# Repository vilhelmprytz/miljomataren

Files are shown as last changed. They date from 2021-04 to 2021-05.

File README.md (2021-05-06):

# miljomataren



| Build | Type | Build Status |
| --- | --- | --- |
| Travis CI | Code Style |  |
| GitLab CI | [Container Registry](https://gitlab.com/vilhelm/miljomataren/container_registry) |  |

Diploma project "miljömätaren". Fullstack web application deployable using Docker.

## Introduction

This project aims to assemble a meter that sits in the air conditioning vents of a car’s instrument panel and shows real-time driving costs, fuel consumption, and carbon emissions using a display.

The project consists of three main components. The first component of this project is the physical gauge installed in the car’s instrument panel. The housing for the gauge is 3D-printed and designed using CAD software (Fusion 360). It contains an LCD connected to a microcontroller board called Arduino MKR GSM 1400. The Arduino board has cellular connectivity (GSM/2G), meaning it can fetch and send data to servers on the internet. To the Arduino, a GPS module with an associated antenna was attached. The Arduino was then able to locate the current position of the automobile and send it to a server using cellular connectivity. The display was used to show the real-time cost and carbon emissions of the current trip, as calculated by the server.

The second component of the project is the web application API (Application Programming Interface). The API was written in a programming language called Python together with a library called Flask. The API was configured to run on a server in the cloud. The Arduino microcontroller was configured to communicate with this API. The API was responsible for user authentication, receiving GPS positioning and calculating carbon emissions and real-time cost of current and past trips. The API uses [Google Sign-In](https://developers.google.com/identity/sign-in/web/sign-in) for authentication.

The third component of this project is the web application frontend. The frontend is a separate application, written separately from the API. The front end was coded to use the API to show statistics to the end-user on a web page. The frontend was coded in JavaScript using a framework called React.

## Structure

| Codebase | Description |
| :--- | :---: |
| [abernathy](abernathy) | Next.js frontend |
| [lowe](lowe) |  Flask backend |
| [delos](delos) | Arduino code |

## Equipment

- Arduino MKR GSM 1400
- LCD module compatible with Hitachi HD44780 driver. [Datasheet](https://www.electrokit.com/uploads/productfile/41014/JHD202C.pdf) for the one used in this project.
- GPS module such as [GPS breakout board FGPMMOPA6H](https://servicepunkten.com/downloads/FGPMMOPA6H_BOB.pdf)

## System Overview

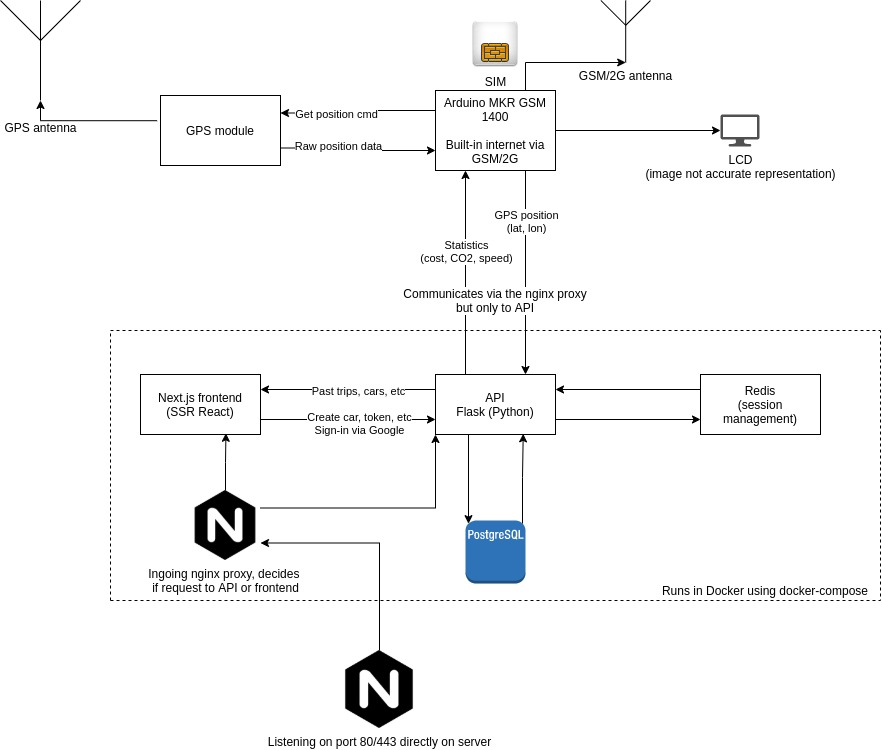
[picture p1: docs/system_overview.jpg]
System Overview


## Circuit Diagram/Schematic

Circuit Diagram/Schematic for physical device.

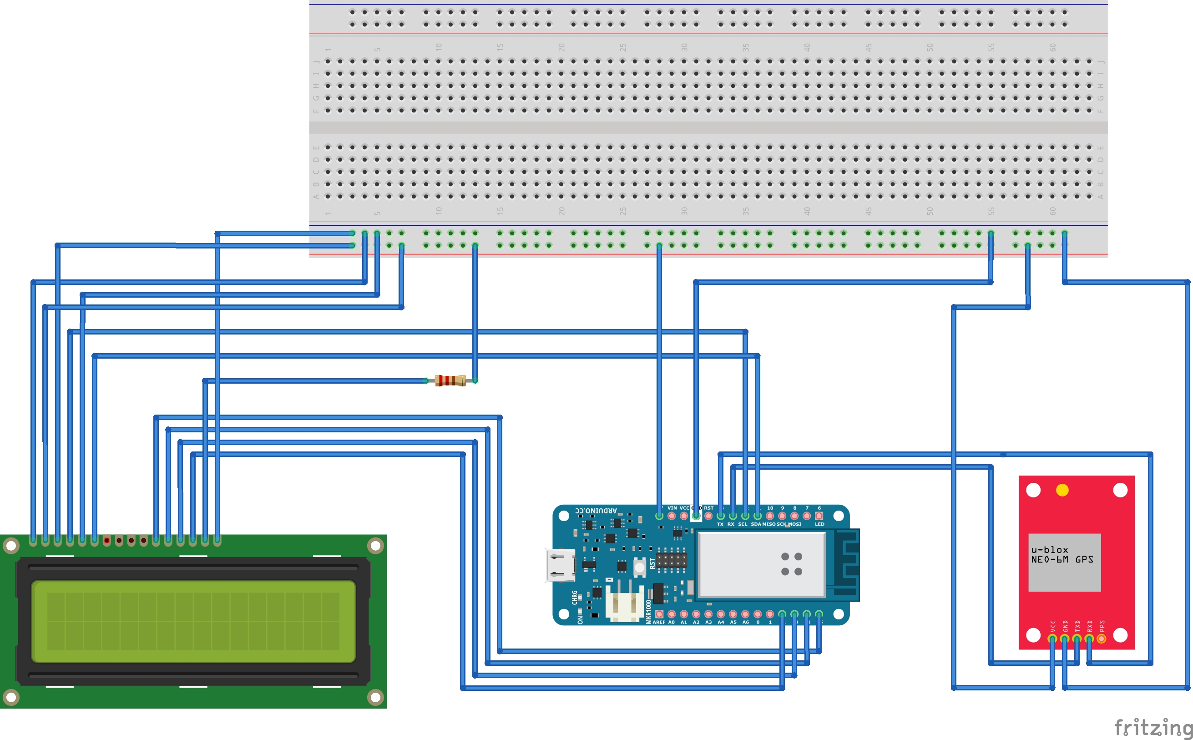
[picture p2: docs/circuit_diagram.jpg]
Circuit Diagram created with Fritzing


Note! The GPS module and LCD showed above may not be identical to the modules used in the project. You may have to adjust settings in the code and/or the wiring to fit your specific GPS module and LCD. The Arduino is labelled as "MKR 1000" but we used the MKR GSM 1400 for the actual device.

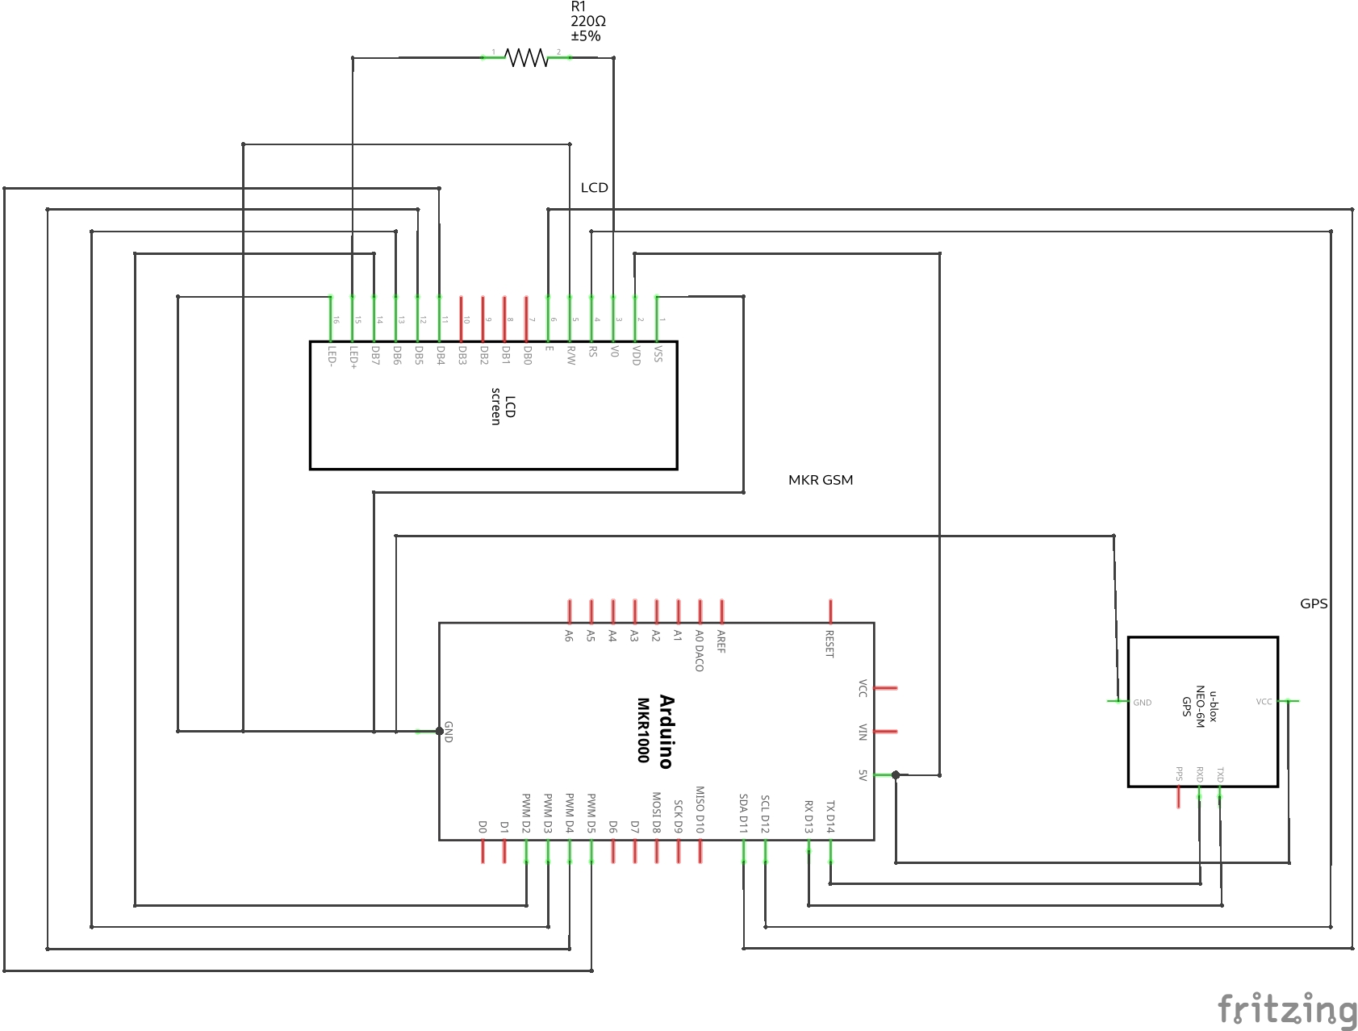
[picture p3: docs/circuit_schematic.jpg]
Circuit Schematic created with Fritzing


## Deploying application

To deploy the application, [Docker](https://docs.docker.com/engine/install/ubuntu/) and [docker-compose](https://docs.docker.com/compose/install/) are both required.

Firstly, you need to configure the application. You can use the `.env.example` as reference, simply copy it to `.env` and modify it to suit your setup.

```bash
cp .env.example .env
vim .env
```

You also need to create a file named `fuel_prices.json` with the current fuel prices (in unit kr/l).

```json
{
  "petrol": 16.14,
  "diesel": 16.27
}
```

Once it's configured, use docker-compose to start the application.

```bash
docker-compose -f prod.yml up -d
```

## Project limitations

### Lack of automated vehicle information

Ideally, the user should only have to enter the registration number of their vehicle and fuel consumption, CO2 emissions and yearly milage of the vehicle should automatically be fetched from [Transportstyrelsen](https://transportstyrelsen.se) (or any other public database). The problem with this is that most APIs are not open to the public and using them induces quite a large cost. We cannot simply afford to do this under the limitations of the project which is why the user has to manually input details about their vehicle. If this application would be commercialized, this would definitely be implementable.

### Fuel consumption on the paper is not real world fuel consumption

This project only uses GPS positioning as well as vehicle information to determine the realtime cost, fuel consumption and CO2 emissions. For a short drive, this isn't an accurate representation of real-world usage. Cars are considerably less fuel-efficient when the engine is cold, thus short trips, where the engine doesn't have time to warm up, will be very inefficient. Our model doesn't reflect that.

Secondly, people drive differently. Aggressive driving and bad planning also leads to less fuel efficiency and is not reflected in this project.

## License

Licensed under the terms of the GNU GPL-3.0 License. See the [license](LICENSE) file.

## Project Authors ✨

- [Vilhelm Prytz](https://github.com/vilhelmprytz), vilhelm@prytznet.se
- [Felix Lindblad](https://github.com/felixlindblad)
- [Ludwig Sjöberg](https://github.com/ludwigsjo)

This codebase is written by Vilhelm Prytz.

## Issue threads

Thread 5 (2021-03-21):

Workout GPS positioning using Arduino MKR GSM

vilhelmprytz, 2021-03-21:
Currently, the Arduino MKR GSM does get network connectivity but I am yet to figure out the GPS part. This needs to be done.

vilhelmprytz, 2021-04-29:
Completed as of commit https://github.com/vilhelmprytz/miljomataren/commit/358f7fee637241e108d270ec559c5ef9e35e2871

Closed 2021-04-29.

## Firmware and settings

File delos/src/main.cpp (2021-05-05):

#include <Arduino.h>
#include <ArduinoJson.h>
#include <Display.h>
#include <Network.h>
#include <Positioning.h>

Network network;
Positioning positioning;
Display display;

uint32_t timer = millis();
uint32_t transition_timer = millis();

bool trip_started = false;
bool show_speed = false;
int trip_id = 0;

// statistics
double trip_cost = 0.0;
double co2_emissions = 0.0;
double speed = 0.0;

// initialize variables
struct Positioning::position currentPos;
struct Network::request positionRequest;
struct Network::request tripRequest;
DynamicJsonDocument position_response(1024);

void setup() {
  // we use the serial for debugging
  Serial.begin(9600);
  Serial.println("Miljömätaren");

  // setup display
  display.setup();

  // setup positioning (GPS)
  display.print("Initializing GPS", "");
  positioning.setup();

  // setup networking
  display.print("Initializing", "network");
  network.setup();
}

void loop() {
  currentPos.success = false;
  positionRequest.success = false;

  // if loop function is OK
  if (positioning.loop() == true) {
    // approximately every 8 seconds or so, get the current position
    if (millis() - timer > 8000) {
      timer = millis(); // reset timer

      // get current position
      currentPos = positioning.get_position();

      if (currentPos.success == true) {
        // we want to start the trip of this is the first request
        if (trip_started == false) {
          display.print("Starting trip", "");
          tripRequest = network.start_trip();

          StaticJsonDocument<384> response;
          deserializeJson(response, tripRequest.response);

          trip_id = response["response"]["id"];

          if (tripRequest.success == false) {
            display.print("Network fail", "Trip not started");
            delay(1000);
          } else {
            trip_started = true;
          }
        }

        positionRequest =
            network.send_position(trip_id, currentPos.lat, currentPos.lon);

        if (positionRequest.success == true) {
          if (positionRequest.code != 200) {
            String code = String(positionRequest.code);
            display.print("HTTP fail", "Status " + code);
          }
        } else {
          display.print("Network fail", "Retrying..");
        }
        // Deserialize the JSON document
        DeserializationError error =
            deserializeJson(position_response, positionRequest.response);

        // Test if parsing succeeds.
        if (error) {
          Serial.print(F("deserializeJson() failed: "));
          Serial.println(error.f_str());
          return;
        }

        trip_cost = position_response["response"]["statistics"]["trip_cost"];
        co2_emissions =
            position_response["response"]["statistics"]["co2_emissions"];
        speed = position_response["response"]["statistics"]["speed"];
      } else {
        display.print("No GPS signal", "Locating..");
      }
    }
  };

  // transition between showing CO2 and speed
  if (millis() - transition_timer > 10000) {
    show_speed = !show_speed;
    transition_timer = millis(); // reset timer
  }

  // update display information
  if (currentPos.success == true && positionRequest.success == true &&
      positionRequest.code == 200) {
    if (show_speed == true) {
      display.print("Trip: " + String(trip_cost) + " kr",
                    String(co2_emissions) + " g CO2");
    } else {
      display.print("Trip: " + String(trip_cost) + " kr",
                    String(speed) + " km/h");
    }
  }
}

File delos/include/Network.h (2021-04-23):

#define ARDUINOJSON_USE_DOUBLE 1

#include "config.h"
#include <Arduino.h>
#include <ArduinoHttpClient.h>
#include <ArduinoJson.h>
#include <MKRGSM.h>

// PIN number to unlock SIM-card
const char PINNUMBER[] = SIM_PINNUMBER;

// APN data
const char GPRS_APN[] = SIM_GPRS_APN;
const char GPRS_LOGIN[] = SIM_GPRS_LOGIN;
const char GPRS_PASSWORD[] = SIM_GPRS_PASSWORD;

// API
const int CAR_ID = API_CAR_ID;
const char TOKEN[] = API_TOKEN;

// Initialize library
GSMSSLClient client;
GPRS gprs;
GSM gsmAccess;

// URL, path and port
char server[] = API_HOST;
int port = 443; // port 443 is the default for HTTPS

// HTTP client library
HttpClient http = HttpClient(client, server, port);

class Network {
public:
  // connection state
  bool connected = false;

  void setup() {
    // Start GSM shield
    // pass SIM pin as parameter to begin
    // pass APN settings to attachGPRS (connect to network)
    while (!connected) {
      if ((gsmAccess.begin(PINNUMBER) == GSM_READY) &&
          (gprs.attachGPRS(GPRS_APN, GPRS_LOGIN, GPRS_PASSWORD) ==
           GPRS_READY)) {
        connected = true;
      } else {
        Serial.println("Not connected");
        delay(1000);
      }
    }

    Serial.println("GSM initialized and GPRS initialized");
  }

  struct request {
    String response;
    int code;
    bool success;
  };

  struct request api_request(String url, String json) {
    Serial.println("POST to " + url);
    http.beginRequest();
    http.post(url);
    http.sendHeader(HTTP_HEADER_CONTENT_TYPE, "application/json");
    http.sendHeader(HTTP_HEADER_CONTENT_LENGTH, json.length());
    http.sendHeader("Authorization", TOKEN);
    http.endRequest();
    http.write((const byte *)json.c_str(), json.length());
    // note: the above line can also be achieved with the simpler line below:
    // client.print(postData);

    // read the status code and body of the response
    int statusCode = http.responseStatusCode();
    String response = http.responseBody();

    Serial.print("POST Status code: ");
    Serial.println(statusCode);
    Serial.print("POST Response: ");
    Serial.println(response);

    return request{response, statusCode, true};
  }

  struct request start_trip() {
    // preperare data as JSON blob
    StaticJsonDocument<16> doc;
    doc["car_id"] = API_CAR_ID;

    // Serialize JSON document
    String json;
    serializeJson(doc, json);

    return api_request("/api/trip", json);
  };

  struct request send_position(int trip_id, float lat, float lon) {
    // preperare data as JSON blob
    StaticJsonDocument<48> doc;
    doc["lat"] = lat;
    doc["lon"] = lon;
    doc["trip_id"] = trip_id;

    // Serialize JSON document
    String json;
    serializeJson(doc, json);

    return api_request("/api/position", json);
  }

  void loop() {
    // if there are incoming bytes available
    // from the server, read them and print them:
    if (client.available()) {
      char c = client.read();
      Serial.print(c);
    }

    // if the server's disconnected, stop the client:
    if (!client.available() && !client.connected()) {
      Serial.println();
      Serial.println("disconnecting.");
      client.stop();
    }
  }
};

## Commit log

2021-03-21 delos: Add arduino code from https://github.com/vilhelmprytz/miljomataren-arduino
2021-04-21 docs: Add initial Fritzing circuit diagram/schematic
    [miljomataren.fzz]
2021-04-22 delos: HTTP fail, not network fail
    [main.cpp]
2021-04-23 delos: initial, almost working, Arduino code
2021-05-03 docs: Add initial fritzing file
    [miljomataren.fzz]
2021-05-05 docs: add system_overview and .drawio file
    [miljomataren.fzz]
2021-05-05 docs: add circuit_diagram and circuit_schematic
    [miljomataren.fzz]
2021-05-05 Add system overview and circuit/schematic diagram to README
2021-05-06 lowe: filter by trip_id on /api/position
2021-05-06 prod.yml: mount local fuel_prices.json to container
